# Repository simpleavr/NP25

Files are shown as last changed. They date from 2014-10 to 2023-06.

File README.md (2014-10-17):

NP Calculator Emulator
======================
Nonpariel Physical (NP) is an standalone calculator microcode emulator

Features
_________________
* selectable rom from HP-21, HP-25C and HP-33C.
* press-n-hold + switch on to select one of the three ROMSs.
* a setup menu to set the default ROM to use, plus ability to set speed (fast / slow).
* both 25C and 33C programs are stored separately.
* a greetings message set and show, handy as a gift item

Description
___________

Compile w/ (example only, substitute w/ your setup path)

/msp430-gcc -Os -Wall -ffunction-sections -fdata-sections -fno-inline-small-functions -Wl,-Map=np25.map,--cref -Wl,--relax -Wl,--gc-sections -I /cygdrive/c/mspgcc-20120406-p20120502/bin/../msp430/include -mmcu=msp430g2553 -o np25.elf np25.c

October 2014, cc
* major code clean-up
* includes power-on switchable roms for 21, 25C and 33C
* allow defaults (rom and speed) be saved
* add greeting message
* rom_34c.h, rom for 34C is included for further development only, not emulated at this version

September 2014, cc
* this is a preview release upon request, project is not bugs free.
* based on TI msp430g25x3 mcu, 16KB flash, 512B ram
* based on work from Eric Smith's nonpariel
* emualtes woodstock or spice core
* this is a hobby project not suitable for any use.
* please observe same GPL licensing terms as the original Nonpariel package
* notice from orignal Nonpareil package

Copyright 1995, 2003, 2004, 2005 Eric L. Smith <eric@brouhaha.com>

Nonpareil is free software; you can redistribute it and/or modify it
under the terms of the GNU General Public License version 2 as
published by the Free Software Foundation.  Note that I am not
granting permission to redistribute or modify Nonpareil under the
terms of any later version of the General Public License.

Nonpareil is distributed in the hope that it will be useful, but
WITHOUT ANY WARRANTY; without even the implied warranty of
MERCHANTABILITY or FITNESS FOR A PARTICULAR PURPOSE.  See the GNU
General Public License for more details.

You should have received a copy of the GNU General Public License
along with this program (in the file "COPYING"); if not, write to the
Free Software Foundation, Inc., 59 Temple Place - Suite 330, Boston,
MA 02111, USA.

Parts list
__________

* msp430g2553 (or other G series dip 20pin devices w/ 16k flash)
* 2x sparkfun 4 digit bubble led module
* 32x tactile buttons
* 1x CR2032 SMD battery holder
* 1x 47k, 1x 1k resistors
* 2x 100nF (104), 1x 1nF (102) capacitor

Application Notes
_________________

* press-n-hold 1st row, 5th column (from top) for hp33C
* press-n-hold 2nd row, 5th column for hp25C
* press-n-hold 3nd row, 5th column for hp21
* press-n-hold 4th row, 4th column for version info
* press-n-hold 1st row, 4th column to show greetings
* press-n-hold 1st row, 3rd column to edit greetings, use 0-9 to enter numbers and letters, Run/Stop to advance digit, Cls to abandon entry
* press-n-hold Pgm/Run toggle button to edit default startup settings, use 'F' key to select rom, 'G' key to select speed, Pgm/Run will save setting and exit setup

Schematic
_________

    * runs off 3V button cell

               MSP430G25x3
             -----------------    
         /|\|                 |  
          | |                 | 
          --|RST  digit 0 P2.6|--\
            |     digit 1 P1.0|--\       digits bus (12)
            |     digit 2 P2.7|-----//--+---------+
            |     digit 3 P1.1|--/      |         ~  3 units of 4 digits bubble led
            |     digit 4 P1.2|--/      |         |
            |     digit 5 P1.3|--/      |    +---------+ +---------+ +---------+
            |     digit 6 P2.0|--/      |    | % % % % | | % % % % | | % % % % |----+
            |     digit 7 P1.4|--/      ~    +---------+ +---------+ +---------+    |
            |     digit 8 P1.5|--/      |                                           |
            |     digit 9 P2.1|--/      | digits bus x 3 scan lines                 |
            |     digit a P1.6|--/      +-----+-----+---/ ~~ /--+-----+-----+-----+ |
            |     digit b P1.7|--/  _=_ | _=_ | _=_ | _/ ~~ /=_ | _=_ | _=_ | _=_ | |
			|      scan X P2.5|-----o o-+-o o-+-o o-+-/ ~~ /o o-+-o o-+-o o-+-o o-+ |
			|      scan Y P2.4|-----o o-+-o o-+-o o-+/ ~~ /-o o-+-o o-+-o o-+-o o-+ |
			|      scan Z P2.3|-----o o-+-o o-+-o o-/ ~~ /+-o o-+-o o-+-o o-+-o o-+ |
            |                 |                                                     ~
			|                 |      (32 tactile button)                            |
            |                 |                                                     |
			|                 |        +--------+                                   |
			|             P2.2|--+---->|CLK ~CLR|---+---- Vcc                       |
			|                 |  |     |       B|---+                               |
			|                 |  |     |  0(d)QA|-\                                 |
			|                 |  |     |  1(f)QB|-\                segments bus (8) |
			|                 |  -     |  2(b)QC|--------------//-------------------+
			|                 | | |    |  3(a)QD|-/
			|                 | | |1k  |  4(g)QE|-/  74hc164 segment driver
			|                 |  -     |  5(e)QF|-/
			|                 |  |     |  6(c)QG|-/
			|                 |  +---->|A 7(h)QH|-/
			|                 |  |     +--------+
            |                 | === (102)    1 wire shift register via RC delay
            |                 | ===  1nF	 to shift 1, Hi-Low-Hi
            +-----------------+  |           to shift 0, Hi-Looooooow-Hi (>20us Lo)
                                ___
                                ///

Additional Notes
________________

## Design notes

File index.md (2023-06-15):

## NP25 Calculator

**msp430 Based Calculator Emulator for the HP-21, HP-25C, and HP-33C Calculators.**

<iframe width="560" height="315" src="https://www.youtube.com/embed/WwPM0slZro4" frameborder="0" allow="autoplay; encrypted-media" allowfullscreen></iframe>
<br><br>

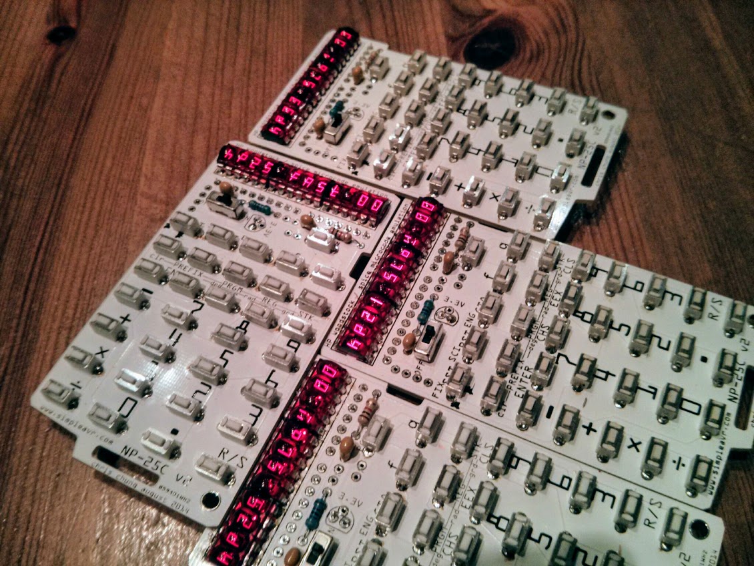
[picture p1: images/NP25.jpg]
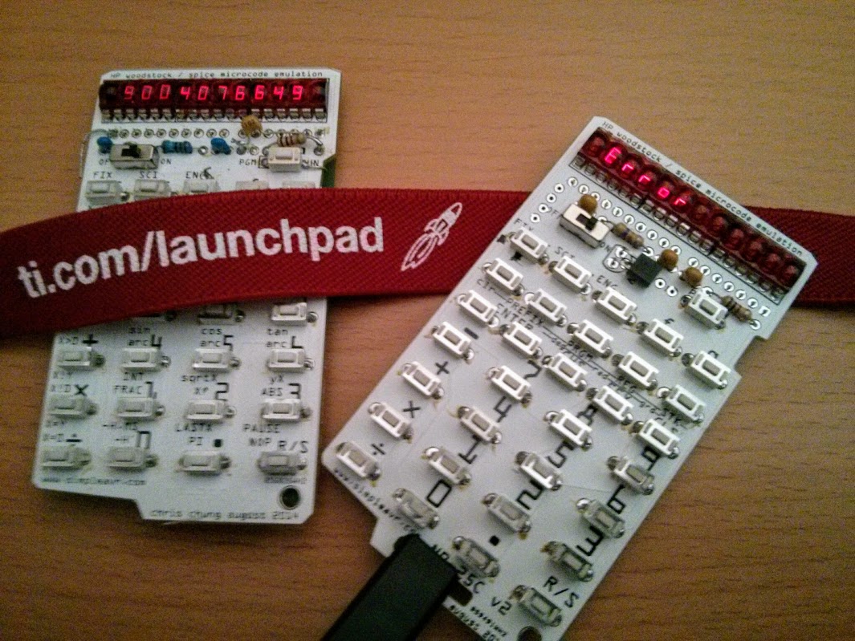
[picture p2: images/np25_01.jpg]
  

### Description

This is a hardware realization of Eric Smith's Nonpareil microcode simulator. 

The objective of the project is to re-create popular 70's RPN calculators such as the HP Woodstock and Spice series. 

Another goal of this project is to have the design as simple as possible so that the project can be re-produced by the average electronic hobbyist. 

A low power MSP430G2553 is used in this project. The DIP profile allows easy soldering. Only through-hole components are used. LED multiplexing is done w/ a 74hc164 shift register. LED modules are direct driven w/ pulsing to eliminate the need of current drivers. 

LED modules are used to mimic the original 70's calculators and gives a retro look to the end product. 

### Application Notes

- press-n-hold 1st row, 5th column (from top) for hp33C
- press-n-hold 2nd row, 5th column for hp25C
- press-n-hold 3nd row, 5th column for hp21
- press-n-hold 4th row, 4th column for version info
- press-n-hold 1st row, 4th column to show greetings
- press-n-hold 1st row, 3rd column to edit greetings, use 0-9 to enter numbers and letters, Run/Stop to advance digit, Cls to abandon entry
- press-n-hold Pgm/Run toggle button to edit default startup settings, use 'F' key to select rom, 'G' key to select speed, Pgm/Run will save setting and exit setup

### Parts and Components

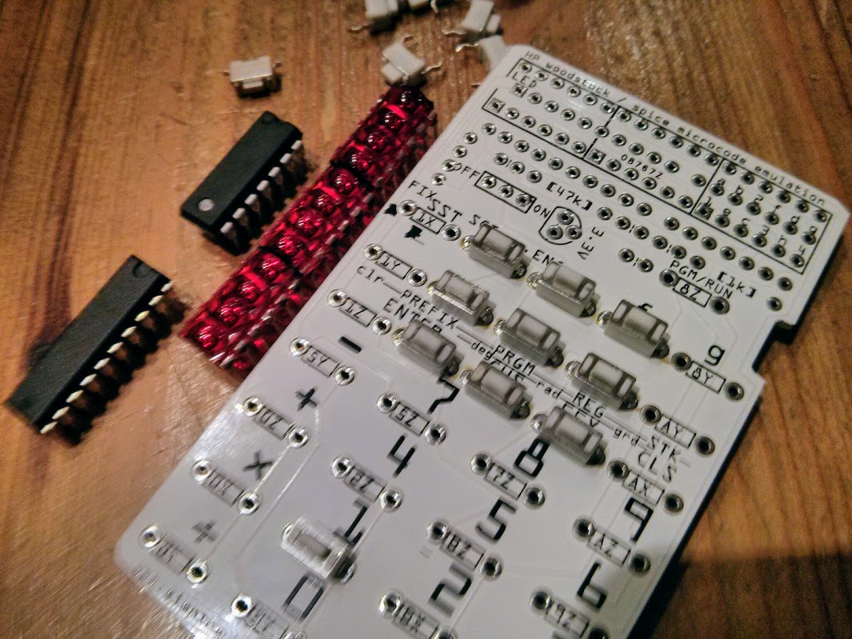
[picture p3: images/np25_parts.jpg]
 

- 1× MSP430G25x3, TI 16bit MCU w/ 16K Flash 512 byte RAM
- 1× 74HC164, TTL shift register
- 3× HP QDSP-6064 LED Module from Sparkfun, 4 digit 7 segment led module
- 32× SMT Tactile Button 6x3mm, May be substituted w/ through-hole buttons
- 1× CR2032 Battery Holder

### Schematic

```
* runs off 3V button cell

           MSP430G25x3
         -----------------
     /|\|                 |
      | |                 |
      --|RST  digit 0 P2.6|--\
        |     digit 1 P1.0|--\       digits bus (12)
        |     digit 2 P2.7|-----//--+---------+
        |     digit 3 P1.1|--/      |         ~  3 units of 4 digits bubble led
        |     digit 4 P1.2|--/      |         |
        |     digit 5 P1.3|--/      |    +---------+ +---------+ +---------+
        |     digit 6 P2.0|--/      |    | % % % % | | % % % % | | % % % % |----+
        |     digit 7 P1.4|--/      ~    +---------+ +---------+ +---------+    |
        |     digit 8 P1.5|--/      |                                           |
        |     digit 9 P2.1|--/      | digits bus x 3 scan lines                 |
        |     digit a P1.6|--/      +-----+-----+---/ ~~ /--+-----+-----+-----+ |
        |     digit b P1.7|--/  _=_ | _=_ | _=_ | _/ ~~ /=_ | _=_ | _=_ | _=_ | |
        |      scan X P2.5|-----o o-+-o o-+-o o-+-/ ~~ /o o-+-o o-+-o o-+-o o-+ |
        |      scan Y P2.4|-----o o-+-o o-+-o o-+/ ~~ /-o o-+-o o-+-o o-+-o o-+ |
        |      scan Z P2.3|-----o o-+-o o-+-o o-/ ~~ /+-o o-+-o o-+-o o-+-o o-+ |
        |                 |                                                     ~
        |                 |      (32 tactile button)                            |
        |                 |                                                     |
        |                 |        +--------+                                   |
        |             P2.2|--+---->|CLK ~CLR|---+---- Vcc                       |
        |                 |  |     |       B|---+                               |
        |                 |  |     |  0(d)QA|-\                                 |
        |                 |  |     |  1(f)QB|-\                segments bus (8) |
        |                 |  -     |  2(b)QC|--------------//-------------------+
        |                 | | |    |  3(a)QD|-/
        |                 | | |1k  |  4(g)QE|-/  74hc164 segment driver
        |                 |  -     |  5(e)QF|-/
        |                 |  |     |  6(c)QG|-/
        |                 |  +---->|A 7(h)QH|-/
        |                 |  |     +--------+
        |                 | === (102)    1 wire shift register via RC delay
        |                 | ===  1nF	 to shift 1, Hi-Low-Hi
        +-----------------+  |           to shift 0, Hi-Looooooow-Hi (>20us Lo)
                            ___
                            ///
```

### Printed Circuit Board

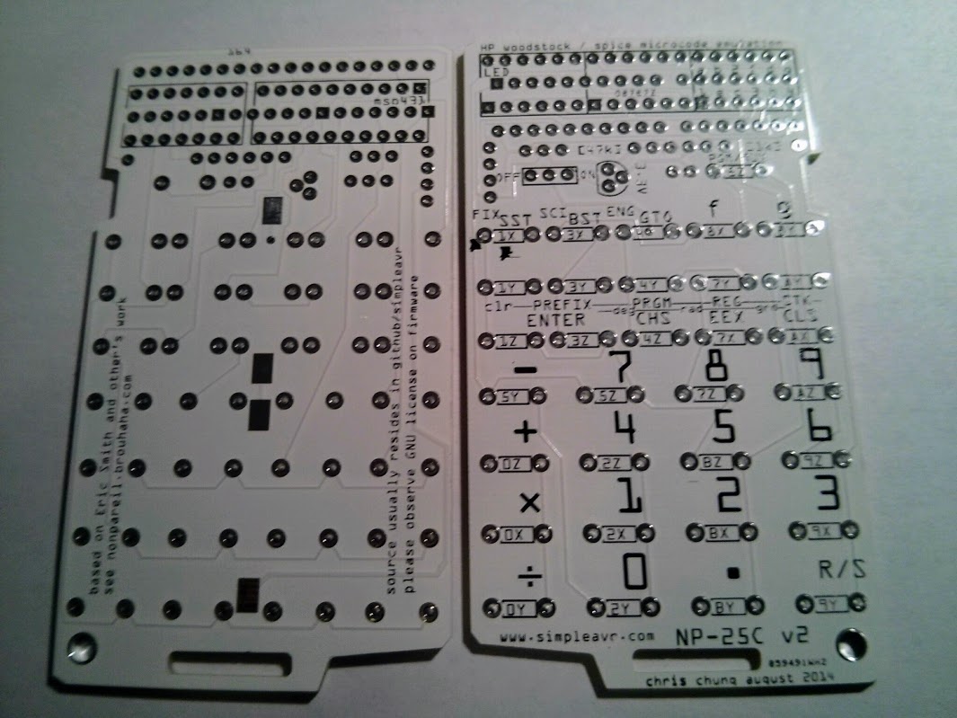
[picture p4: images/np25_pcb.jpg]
 

Create PCB board from the Fritzing design file included in my [github repository](https://github.com/simpleavr/NP25).

You will need to install [Fritzing](http://fritzing.org/home/) and learn how to use it.

Fabricate PCB yourself or order from a FAB house (export Gerber files from Fritzing).

Acquire parts from the components list.

### Soldering

The two layer PCB was designed to minimize component space, and as such, components are placed on both side of the PCB. The ICs and LED modules actually intrudes into each other's footprint as they are through hole components. To address this issue, both the ICs and the LED modules need to have their pins trimmed so that they do not protrude into the other side of the PCB.

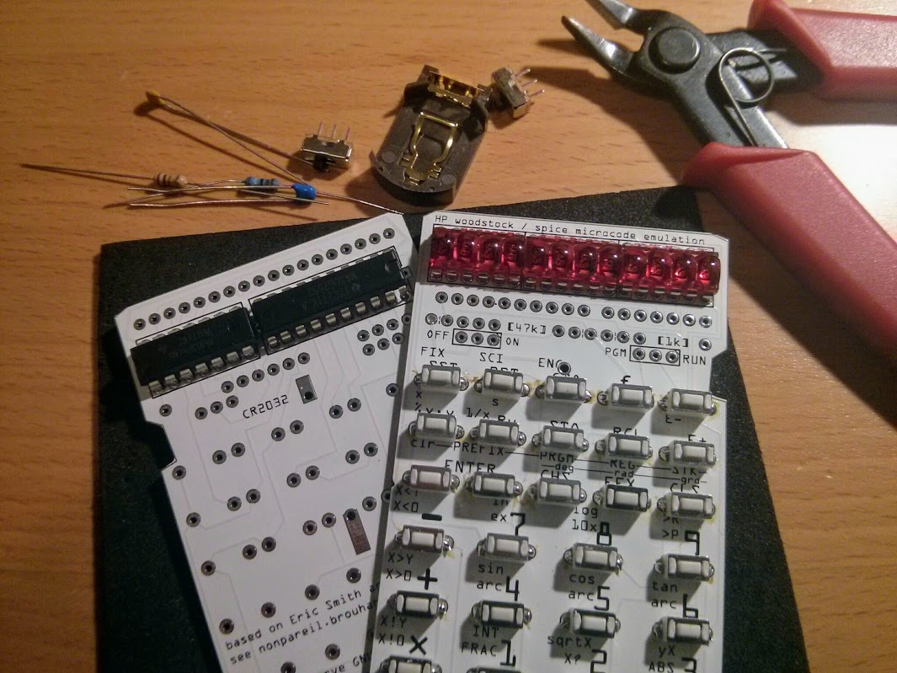
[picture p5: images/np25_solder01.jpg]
 

It is best to place and solder the LED modules first. There are three of them and when finished soldering, use a wire cutter / trimmer to trim off the pins on the other side. This will allow proper placement of the ICs.

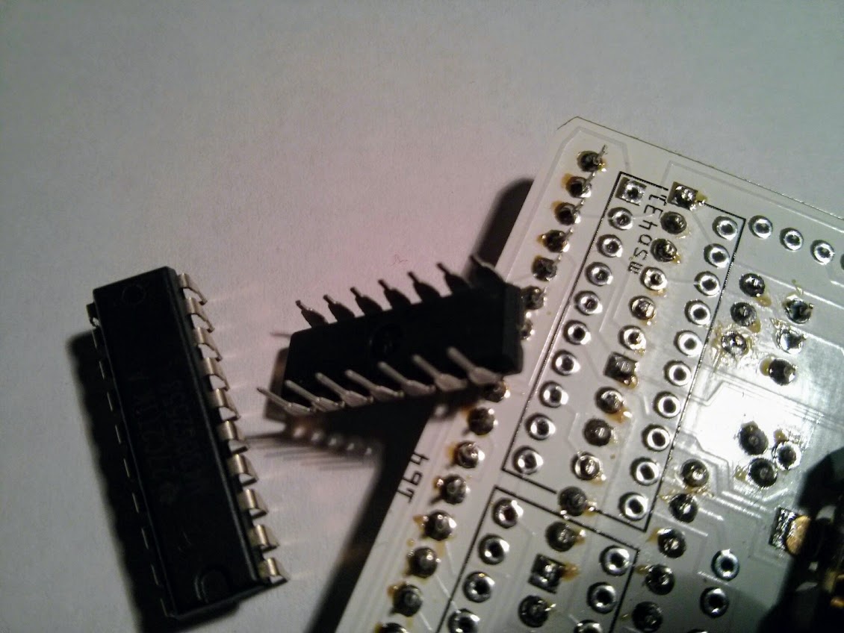
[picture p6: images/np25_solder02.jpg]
 

Next we need to trim the IC pins before placing them onto the PCB. As the other side of the through holes are blocked by the LED modules, they will not fit without trimming the pins.

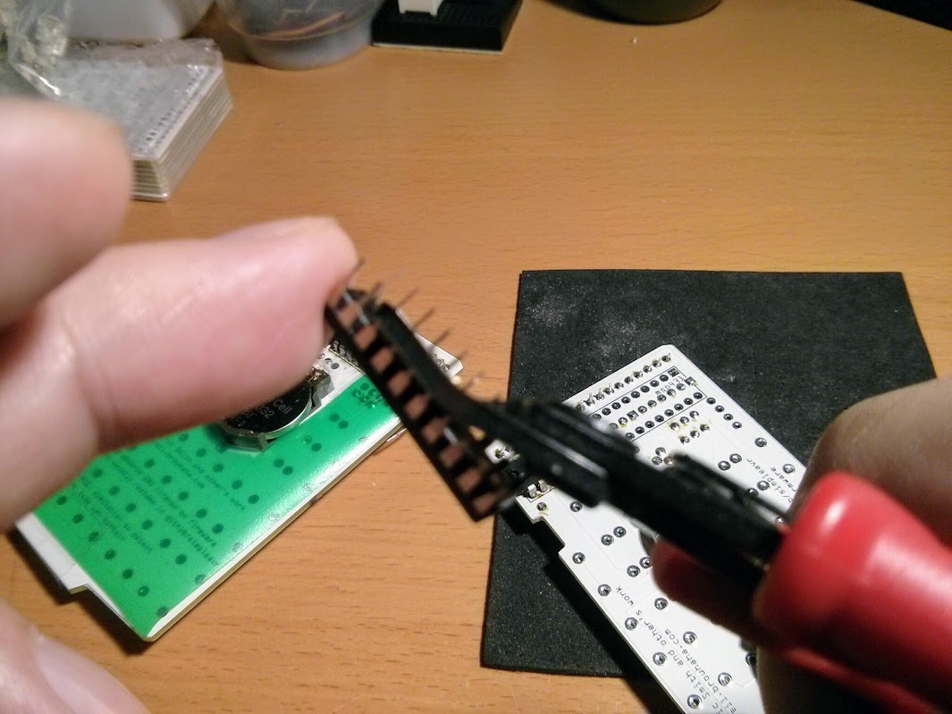
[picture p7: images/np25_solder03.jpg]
 

With the ICs placed on the PCB. We could commence soldering them. This has to be done on the IC component (back) side instead of the usual solder (front) side. This is because the LED modules on the front side block the holes.

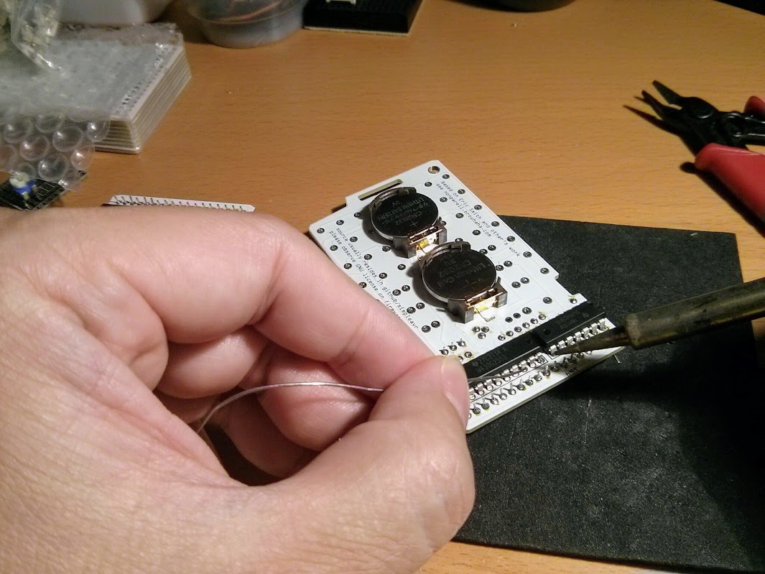
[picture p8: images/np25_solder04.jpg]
 

The rest of the components including the tactile switches and other passive components can be soldered the usual way.

### Software and Programming Tools

Acquire a MSP430 MCU programmer. We need this to program the MCU. Easiest and least expensive way is to get a [TI LaunchPad G2](http://www.ti.com/tool/MSP-EXP430G2) and use it as a programmer.

Download and install GCC compiler for MSP430. There are instructions on the web. You can also [install Energia](http://energia.nu) and use the GCC compiler in the bundle.

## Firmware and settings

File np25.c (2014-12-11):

/*

Chris Chung August 2014, simpleavr@gmail.com
nonpariel physical (NP) is an standalone calculator microcode emulator;

Compile w/ (example only, substitute w/ your setup path)

/msp430-gcc -Os -Wall -ffunction-sections -fdata-sections -fno-inline-small-functions -Wl,-Map=np25.map,--cref -Wl,--relax -Wl,--gc-sections -I /cygdrive/c/mspgcc-20120406-p20120502/bin/../msp430/include -mmcu=msp430g2553 -o np25.elf np25.c

September 2014, cc
. this is a preview release upon request, project is not bugs free.

. based on TI msp430g25x3 mcu, 16KB flash, 512B ram
. based on work from Eric Smith's nonpariel
. emualtes woodstock or spice core
. this is a hobby project not suitable for any use.
. please observe same GPL licensing terms as the original Nonpariel package
. notice from orignal Nonpareil package

Copyright 1995, 2003, 2004, 2005 Eric L. Smith <eric@brouhaha.com>

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
You should have received a copy of the GNU General Public License
along with this program (in the file "COPYING"); if not, write to the
Free Software Foundation, Inc., 59 Temple Place - Suite 330, Boston,
MA 02111, USA.
*/

//#define C_SPICE
#define EMBEDDED
#define C_STANDALONE

#include <inttypes.h>
#include <stdbool.h>
#include <stdint.h>
#include <stdio.h>
#include <stdlib.h>
#include <string.h>

#ifdef EMBEDDED

#define G2553
#define MHZ	12

#include <msp430.h>
//#include "../local/common.h"
//
#define ___use_cal_clk(x)	\
BCSCTL1 = CALBC1_##x##MHZ;	\
DCOCTL  = CALDCO_##x##MHZ;

#define __use_cal_clk(x)	___use_cal_clk(x)
//

#ifdef C_STANDALONE
static volatile uint16_t _ticks = 0;
static volatile uint8_t _clicks = 1;

/*

               MSP430G25x3
             -----------------    
         /|\|                 |  
          | |                 | 
          --|RST  digit 0 P2.6|--\
            |     digit 1 P1.0|--\       digits bus (12)
            |     digit 2 P2.7|-----//--+---------+
            |     digit 3 P1.1|--/      |         ~  3 units of 4 digits bubble led
            |     digit 4 P1.2|--/      |         |
            |     digit 5 P1.3|--/      |    +---------+ +---------+ +---------+
            |     digit 6 P2.0|--/      |    | % % % % | | % % % % | | % % % % |----+
            |     digit 7 P1.4|--/      ~    +---------+ +---------+ +---------+    |
            |     digit 8 P1.5|--/      |                                           |
            |     digit 9 P2.1|--/      | digits bus x 3 scan lines                 |
            |     digit a P1.6|--/      +-----+-----+---/ ~~ /--+-----+-----+-----+ |
            |     digit b P1.7|--/  _=_ | _=_ | _=_ | _/ ~~ /=_ | _=_ | _=_ | _=_ | |
			|      scan X P2.5|-----o o-+-o o-+-o o-+-/ ~~ /o o-+-o o-+-o o-+-o o-+ |
			|      scan Y P2.4|-----o o-+-o o-+-o o-+/ ~~ /-o o-+-o o-+-o o-+-o o-+ |
			|      scan Z P2.3|-----o o-+-o o-+-o o-/ ~~ /+-o o-+-o o-+-o o-+-o o-+ |
            |                 |                                                     ~
			|                 |      (32 tactile button)                            |
            |                 |                                                     |
			|                 |        +--------+                                   |
			|             P2.2|--+---->|CLK ~CLR|---+---- Vcc                       |
			|                 |  |     |       B|---+                               |
			|                 |  |     |  0(d)QA|-\                                 |
			|                 |  |     |  1(f)QB|-\                segments bus (8) |
			|                 |  -     |  2(b)QC|--------------//-------------------+
			|                 | | |    |  3(a)QD|-/
			|                 | | |1k  |  4(g)QE|-/  74hc164 segment driver
			|                 |  -     |  5(e)QF|-/
			|                 |  |     |  6(c)QG|-/
			|                 |  +---->|A 7(h)QH|-/
			|                 |  |     +--------+
            |                 | === (102)    1 wire shift register via RC delay
            |                 | ===  1nF	 to shift 1, Hi-Low-Hi
            +-----------------+  |           to shift 0, Hi-Looooooow-Hi (>20us Lo)
                                ___
                                ///

               74hc164
               o---------+
               |A     Vcc|
               |B      QH|
               |QA     QG|
               |QB     QF|
               |QC     QE|
               |QD   ~CLR|
               |Gnd   CLK|
               +---------+

	4 digit bubble led from sparkfun
    +--+--+--+--+--+ 
   |a  b  2  f  d  g|
   |1  e  c  3  h  4|
    +--+--+--+--+--+ 

	msp430g25x3 pinout (a=port1, b=port2)
    +--+--+--+--+--+--+--+--+--+ 
   |- b6 b7 CK IO a7 a6 b5 b4 b3|
   |                            |
   |+ a0 a1 a2 a3 a4 a5 b0 b1 b2|
    o--+--+--+--+--+--+--+--+--+ 
*/


#define C_PCB

#ifdef C_PCB

static const 
//__attribute__ ((section (".data_fe"))) 
uint8_t digit_map_p1[] = {
	0x00, 1<<0, 0x00, 1<<1,
	1<<2, 1<<3, 0x00, 1<<4,
	1<<5, 0x00, 1<<6, 1<<7,
};

static const 
//__attribute__ ((section (".data_fe"))) 
const uint8_t digit_map_p2[] = {
	1<<6, 0x00, 1<<7, 0x00,
	0x00, 0x00, 1<<0, 0x00,
	0x00, 1<<1, 0x00, 0x00,
};

#define CLK_LOW	P2OUT &= ~BIT2
#define CLK_HI	P2OUT |= BIT2

#define SPIN	P2IN
#define SPOUT	P2OUT
#define SPREN	P2REN
#define SPDIR	P2DIR

#define SCANX	BIT5
#define SCANY	BIT4
#define SCANZ	BIT3
#define ALL_SCANS	(SCANX|SCANY|SCANZ)

#define SEG_D	BIT0
#define SEG_F	BIT1
#define SEG_B	BIT2
#define SEG_A	BIT3
#define SEG_G	BIT4
#define SEG_E	BIT5
#define SEG_C	BIT6
#define SEG_H	BIT7

#else

static const uint8_t digit_map_p1[] = {
	1<<0, 1<<7, 1<<1, 1<<2,
	0, 0, 0, 0,
	0, 0, 0, 0,
};

static const uint8_t digit_map_p2[] = {
	0, 0, 0, 0,
	1<<0, 1<<1, 1<<2, 1<<3,
	1<<4, 1<<5, 1<<6, 1<<7,
};

#define CLK_LOW	P1OUT &= ~BIT3
#define CLK_HI	P1OUT |= BIT3

#define SPIN	P1IN
#define SPOUT	P1OUT
#define SPREN	P1REN
#define SPDIR	P1DIR
#define SCANX	BIT4
#define SCANY	BIT5
#define SCANZ	BIT6
#define ALL_SCANS	(SCANX|SCANY|SCANZ)

#define SEG_A	BIT0
#define SEG_B	BIT5
#define SEG_C	BIT2
#define SEG_D	BIT6
#define SEG_E	BIT3
#define SEG_F	BIT4
#define SEG_G	BIT7
#define SEG_H	BIT1

#endif

#define ALL_DIGITS_P1	\
   (digit_map_p1[0]|digit_map_p1[1]|digit_map_p1[2]|digit_map_p1[3]|	\
	digit_map_p1[4]|digit_map_p1[5]|digit_map_p1[6]|digit_map_p1[7]|	\
	digit_map_p1[8]|digit_map_p1[9]|digit_map_p1[10]|digit_map_p1[11])
#define ALL_DIGITS_P2	\
   (digit_map_p2[0]|digit_map_p2[1]|digit_map_p2[2]|digit_map_p2[3]|	\
	digit_map_p2[4]|digit_map_p2[5]|digit_map_p2[6]|digit_map_p2[7]|	\
	digit_map_p2[8]|digit_map_p2[9]|digit_map_p2[10]|digit_map_p2[11])

static const 
//__attribute__ ((section (".data_fe"))) 
uint8_t seg_map[] = {
   SEG_A|SEG_B|SEG_C|SEG_D|SEG_E|SEG_F,
   SEG_B|SEG_C,
   SEG_A|SEG_B|SEG_D|SEG_E|SEG_G,
   SEG_A|SEG_B|SEG_C|SEG_D|SEG_G,
   SEG_B|SEG_C|SEG_F|SEG_G,
   SEG_A|SEG_C|SEG_D|SEG_F|SEG_G,
   SEG_A|SEG_C|SEG_D|SEG_E|SEG_F|SEG_G,
   SEG_A|SEG_B|SEG_C,
   SEG_A|SEG_B|SEG_C|SEG_D|SEG_E|SEG_F|SEG_G,
   SEG_A|SEG_B|SEG_C|SEG_D|SEG_F|SEG_G,
   SEG_E|SEG_G,	// r, H/F, o, p, e, blank
//#ifdef C_SPICE
//#else
   SEG_A|SEG_E|SEG_F|SEG_G, 			
//#endif
   SEG_C|SEG_D|SEG_E|SEG_G,
   SEG_A|SEG_B|SEG_E|SEG_F|SEG_G,
   SEG_A|SEG_D|SEG_E|SEG_F|SEG_G,
   0x00,
   SEG_B|SEG_C|SEG_E|SEG_F|SEG_G, 		// for spice as 0xb
   //________________ a to z
   SEG_A|SEG_B|SEG_C|SEG_E|SEG_F|SEG_G,	// A
   SEG_C|SEG_D|SEG_E|SEG_F|SEG_G,		// b
   SEG_D|SEG_E|SEG_G,					// c
   SEG_B|SEG_C|SEG_D|SEG_E|SEG_G,		// d
   SEG_A|SEG_D|SEG_E|SEG_F|SEG_G,		// E
   SEG_A|SEG_E|SEG_F|SEG_G,				// F
   SEG_A|SEG_C|SEG_D|SEG_E|SEG_F,		// G
   SEG_C|SEG_E|SEG_F|SEG_G,				// h
   SEG_E|SEG_F,							// i
   SEG_B|SEG_C|SEG_D,					// j
   SEG_D|SEG_F|SEG_G,					// k
   SEG_D|SEG_E|SEG_F,					// L
   SEG_A|SEG_C|SEG_E,					// m
   SEG_C|SEG_E|SEG_G,					// n
   SEG_C|SEG_D|SEG_E|SEG_G,				// o
   SEG_A|SEG_B|SEG_E|SEG_F|SEG_G,		// P
   SEG_A|SEG_B|SEG_C|SEG_F|SEG_G,		// q
   SEG_E|SEG_G,							// r
   SEG_A|SEG_C|SEG_D|SEG_F|SEG_G,		// S
   SEG_D|SEG_E|SEG_F|SEG_G,				// t
   SEG_C|SEG_D|SEG_E,					// u
   SEG_C|SEG_D|SEG_E|SEG_F,				// v
   SEG_B|SEG_D|SEG_F,					// w
   SEG_B|SEG_C|SEG_E|SEG_F|SEG_G,		// X
   SEG_B|SEG_C|SEG_D|SEG_F|SEG_G,		// y
   SEG_A|SEG_B|SEG_D|SEG_E|SEG_G,		// Z
   SEG_A|SEG_D|SEG_E|SEG_F|SEG_G,		// [
   SEG_A|SEG_B|SEG_F,					// ^
   SEG_A|SEG_B|SEG_C|SEG_D|SEG_G,		// ]
   SEG_C|SEG_F|SEG_G,					// blackslash
   SEG_D,								// _
   SEG_B,								// '
};

/*
keys layout
	// 25
	" SST  BST  GTO   F    G ",	// 0xb3, 0xb2, 0xb1, 0xb0, 0xb4
	" X.Y  RV   STO  RCL  E+ ",	// 0x43, 0x42, 0x41, 0x40, 0x44
	" ETR  ETR  CHS  EEX  CLX",	// 0xd3,       0xd1, 0xd0, 0xd4
	"  -     7     8      9  ",	// 0x63, 0x62, 0x61, 0x60
	"  +     4     5      6  ",	// 0x93, 0x92, 0x91, 0x90
	"  x     1     2      3  ",	// 0x73, 0x72, 0x71, 0x70
	"  /     0     .     R/S ", // 0xa3, 0xa2, 0xa1, 0xa0

	// 34c
	"  A    B   GSB   F    G ",	// 0x34, 0x33, 0x32, 0x31, 0x30
	" X.Y  GTO  STO  RCL   h ",	// 0x94, 0x93, 0x92, 0x91, 0x90
	" ETR  ETR  CHS  EEX  CLX",	// 0x73,       0x72, 0x71, 0x70
	"  -     7     8      9  ",	// 0xa3, 0xa2, 0xa1, 0xa0
	"  +     4     5      6  ",	// 0x43, 0x42, 0x41, 0x40
	"  x     1     2      3  ",	// 0xd3, 0xd2, 0xd1, 0xd0
	"  /     0     .     R/S ", // 0x63, 0x62, 0x61, 0x60

raw scancode on pcb version, code is digit * 4 + [123] for [XYZ]

                       [8Z]	            ,35,
   [1X] [3X] [4X] [8X] [8Y]	, 5,13,17,33,34,
   [1Y] [3Y] [4Y] [7Y] [aY] , 6,14,18,30,42,
   [1Z] [3Z] [4Z] [7X] [aX] , 7,15,19,29,41,
   [5Y]  [5Z]   [7Z]   [aZ] ,22,   23,31,43,
   [0Z]  [2Z]   [bZ]   [9Z] , 3,   11,47,39,
   [0X]  [2X]   [bX]   [9X] , 1,    9,45,37,
   [0Y]  [2Y]   [bY]   [9Y] , 2,   10,46,38,
   scan lines X, Y, Z

*/
#else

#include "../local/uart.h"
#define putchar(x)	uart_putc(x)

#endif

#else

#include <unistd.h>
#include <sys/select.h>
#include <termios.h>

#endif

#ifdef C_STANDALONE
#else 

static const uint8_t key_map[256] = {
	// 25c
	0x00, 0x00, 0x00, 0x00, 0x00, 0x00, 0x00, 0x00, 0x00, 0x00, 0x00, 0x00, 0x00, 0x90, 0x00, 0x00,	// 0x0f
	0x00, 0x00, 0x00, 0x00, 0x00, 0x00, 0x00, 0x00, 0x00, 0x00, 0x00, 0x00, 0x00, 0x00, 0x00, 0x00,	// 0x1f
	0xd3, 0x00, 0x00, 0x00, 0x00, 0x00, 0x00, 0x00, 0x00, 0x00, 0x73, 0xa3, 0x00, 0x63, 0x91, 0x93,	// 0x2f
	0x92, 0x72, 0x71, 0x70, 0xa2, 0xa1, 0xa0, 0x62, 0x61, 0x60, 0x00, 0x00, 0x00, 0x00, 0x00, 0x00,	// 0x3f
	0x00, 0x00, 0x00, 0x00, 0x00, 0x00, 0x00, 0x00, 0x00, 0x00, 0x00, 0x00, 0x00, 0x00, 0x00, 0x00,	// 0x4f
	0x00, 0x00, 0x00, 0x00, 0x00, 0x00, 0x00, 0x00, 0x00, 0x00, 0x00, 0x00, 0x00, 0x00, 0x00, 0x00,	// 0x5f
	0x00, 0xb3, 0x00, 0xd4, 0xb1, 0x41, 0xb0, 0xb4, 0x00, 0x00, 0x00, 0x00, 0x00, 0x00, 0x00, 0x00,	// 0x6f
	0x00, 0x43, 0x40, 0xb2, 0x44, 0x00, 0x00, 0x42, 0xd0, 0x00, 0xd1, 0x00, 0x00, 0x00, 0x00, 0x00,	// 0x7f
	// 34c
	0x00, 0x00, 0x00, 0x00, 0x00, 0x00, 0x00, 0x00, 0x00, 0x00, 0x00, 0x00, 0x00, 0x40, 0x00, 0x00,	// 0x0f
	0x00, 0x00, 0x00, 0x00, 0x00, 0x00, 0x00, 0x00, 0x00, 0x00, 0x00, 0x00, 0x00, 0x00, 0x00, 0x00,	// 0x1f
	0x73, 0x00, 0x00, 0x00, 0x00, 0x00, 0x00, 0x00, 0x00, 0x00, 0xd3, 0x63, 0x00, 0xa3, 0x41, 0x43,	// 0x2f
	0x42, 0xd2, 0xd1, 0xd0, 0x62, 0x61, 0x60, 0xa2, 0xa1, 0xa0, 0x00, 0x00, 0x00, 0x00, 0x00, 0x00,	// 0x3f
	0x00, 0x00, 0x00, 0x00, 0x00, 0x00, 0x00, 0x00, 0x00, 0x00, 0x00, 0x00, 0x00, 0x00, 0x00, 0x00,	// 0x4f
	0x00, 0x00, 0x00, 0x00, 0x00, 0x00, 0x00, 0x00, 0x00, 0x00, 0x00, 0x00, 0x00, 0x00, 0x00, 0x00,	// 0x5f
	0x00, 0x34, 0x00, 0x70, 0x32, 0x92, 0x31, 0x30, 0x00, 0x00, 0x00, 0x00, 0x00, 0x00, 0x00, 0x00,	// 0x6f
	0x00, 0x94, 0x91, 0x33, 0x90, 0x00, 0x00, 0x93, 0x71, 0x00, 0x72, 0x00, 0x00, 0x00, 0x00, 0x00,	// 0x7f
};

#endif

#define __USE_RAM	32	// our highest model 33c has 32 units

#include "rom_21.h"
#include "rom_25.h"
#include "rom_33c.h"
#include "np25.h"

static volatile uint8_t _pgm_run=1;
static volatile uint8_t _state=0;
static volatile uint8_t _key=0;
static int8_t _greetings[12];

#define ST_RAM_LOADED 		BIT7
#define ST_KEY_PRESSED		BIT6
#define ST_KEY_RELEASED		BIT5
#define ST_ALPHA_MSG		BIT4
#define ST_HW_SLOW			BIT3
#define ST_HW_TEST			BIT2
#define ST_ROM_BIT1			BIT1
#define ST_ROM_BIT0  		BIT0
#define ST_ROM				(ST_ROM_BIT1|ST_ROM_BIT0)

/*
  base=142
  64+64+64
  4 blocks 112+112+112+112=448
  142 + [224] = 366 used + 32 ram_reserve = 392
  > offset 224
  get block 2+3 (224) write 192 to info BCD, 32 into ram_reserve
*/

//________________________________________________________________________________
void flash_write(uint8_t bank, char *src, uint8_t cnt) {
	char *flash = (char*) 0x1040;
	if (bank) flash += 0x40;
	FCTL2 = FWKEY+FSSEL0+FN2;
	FCTL1 = FWKEY+ERASE;
	FCTL3 = FWKEY;
	*flash = 0;

	FCTL1 = FWKEY+WRT; 

	uint8_t i;
	for (i=0;i<cnt;i++) *flash++ = *src++;
	*flash++ = _state;
	if (!bank)
		for (i=0;i<12;i++) *flash++ = _greetings[i];

	FCTL1 = FWKEY;
	FCTL3 = FWKEY+LOCK; 
}

#define _MSG_POS	act_reg->f
#define _MSG_LEN	act_reg->p
#define _EDIT_POS 	act_reg->key_buf
#define _MSG_PTR	act_reg->rom
#define _LAST_KEY	act_reg->flags

//volatile uint8_t _MSG_POS=0, _MSG_LEN=0;
//volatile const char *_MSG_PTR=0;

/*
hp-25 5
pos 11 digit 0(x).......     11(h)
pos 10 digit 0(x).......10(h)11(p)
pos 2 digit 0(x)...9(h)10(p)11(-)
*/


//________________________________________________________________________________
uint8_t char_at_digit(uint8_t digit) {
	uint8_t seg=0;
	if ((digit==_EDIT_POS) && (_ticks&0x200)) return 0;
	if (digit>=_MSG_POS) {
		uint8_t i = digit-_MSG_POS;
		if (i < _MSG_LEN) {
			if (_MSG_PTR[i] >= '0') { if (i >= 'A')
					seg = seg_map[_MSG_PTR[i] - 32 - '0'];
				else
					seg = seg_map[_MSG_PTR[i] - '0'];
			}//if
		}//if
	}//if
	return seg;
}
//________________________________________________________________________________
void show_msg(const uint8_t *msg, uint8_t delay_units) {

	_MSG_PTR = msg;
	while (*msg++) _MSG_LEN++;
	_MSG_POS = 11;
	_state |= ST_ALPHA_MSG;
	//______ accelerate.....brake 6,5,4,3,2,1,2,3,4,5,6
	//                            b,a,9,8,7,6,5,4,3,2,1
	while (_MSG_POS--) {
		_clicks = _MSG_POS>=6 ? _MSG_POS-5 : 6-_MSG_POS;
		LPM0;
	}//while
	_MSG_POS = 0;

	if (delay_units) _clicks = delay_units;
	LPM0;
	_state &= ~ST_ALPHA_MSG;
}

//________________________________________________________________________________
int main() {

#ifdef EMBEDDED
    WDTCTL  = WDTPW + WDTHOLD; 	// Stop WDT
	__use_cal_clk(MHZ);
	//FCTL2 = FWKEY + FSSEL0 + FN1;	// MCLK/3 for Flash Timing Generator
	FCTL2 = FWKEY + FSSEL0 + FN2;	// for 12Mhz

#ifdef C_STANDALONE

	TA0CCR0  = MHZ * 1000;		// start w/ 1ms
	TA0CCTL0 = CCIE;
	TA0CTL = TASSEL_2 + MC_2;	// SMCLK, cont.

	P1SEL = P2SEL = 0;

	P1OUT = ALL_DIGITS_P1;
	P2OUT = ALL_DIGITS_P2;
	P1DIR = P2DIR = 0xff;

	SPOUT |= ALL_SCANS;
	SPREN |= ALL_SCANS;
	SPDIR &= ~ALL_SCANS;

#else
	uint8_t usage = 0;
	uart_init();
#endif

    __bis_SR_register(GIE);

#else
	set_conio_terminal_mode();

#endif

 
	/*
	key_map['0'] = 0x92; key_map['1'] = 0x72; key_map['2'] = 0x71; key_map['3'] = 0x70;
	key_map['4'] = 0xa2; key_map['5'] = 0xa1; key_map['6'] = 0xa0; key_map['7'] = 0x62;
	key_map['8'] = 0x61; key_map['9'] = 0x60; key_map['.'] = 0x91; key_map['-'] = 0x63;
	key_map['+'] = 0xa3; key_map['*'] = 0x73; key_map['/'] = 0x93; key_map['\r'] = 0x90;	// run/stop
	key_map['a'] = 0xb3; key_map['s'] = 0xb2; key_map['d'] = 0xb1; key_map['f'] = 0xb0; key_map['g'] = 0xb4; // SST BST GTO F   G
	key_map['q'] = 0x43; key_map['w'] = 0x42; key_map['e'] = 0x41; key_map['r'] = 0x40; key_map['t'] = 0x44; // X.Y RV  STO RCL E+
	key_map[' '] = 0xd3; key_map['z'] = 0xd1; key_map['x'] = 0xd0; key_map['c'] = 0xd4;					     // ETR ETR CHS EEX CLX
	*/
#define RAM_OFFSET	(7*9)
#define RAM_SIZE	(7*7)		// 49 program steps

	woodstock_clear_memory();
	//______ load from flash, we just need the status config, but we load everything since
	//       we might need to write it back and flash always write in full blocks
	uint8_t idx = RAM_SIZE + 1 + 12;	// 49 program steps + config byte + 12 byte greeting
	while (idx--) ((char*) act_reg->ram)[idx+RAM_OFFSET] = *((char*) (0x1040+idx));
	_state = ((char*) (act_reg->ram))[RAM_OFFSET+RAM_SIZE] & (ST_HW_SLOW|ST_ROM);

	for (idx=0;idx<12;idx++) _greetings[idx] = ((uint8_t*) act_reg->ram)[RAM_OFFSET+50+idx];
	_MSG_PTR = (uint8_t*) _greetings;

	LPM0;

	while (_key == 35) _state |= ST_HW_TEST;		// pgm key pressed, enter setup

	_EDIT_POS = 99;
	uint8_t save_state = _state;
	switch (_key) {
		//
		case 17: 	// "goto" key for edit easter egg message
			while (!(_state&ST_KEY_RELEASED)) __asm("nop");
			_state &= ~ST_KEY_RELEASED;
			{
				uint8_t *p= (uint8_t*) _MSG_PTR;
				//uint8_t i=0;
				_EDIT_POS = 0;
				_MSG_POS = 0;
				_MSG_LEN = 12;
				_LAST_KEY = 99;
				_state |= ST_ALPHA_MSG;		// start show
				while (1) {
					LPM0;					// wait key
					uint8_t k = _key;
					if (k == 41) break;
					if (k == 38) {
						_EDIT_POS++;
						p++;
						_LAST_KEY = 99;
						if (_EDIT_POS>=12) {
							//__________ the last 12 bytes are the greetings
							flash_write(0, (char*) act_reg->ram + RAM_OFFSET, RAM_SIZE);
							break;
						}//if
					}//if
					switch (k) {
						case 10: k = 0; break;
						case 9:  k = 1; break;
						case 45: k = 2; break;
						case 37: k = 3; break;
						case 11: k = 4; break;
						case 47: k = 5; break;
						case 39: k = 6; break;
						case 23: k = 7; break;
						case 31: k = 8; break;
						case 43: k = 9; break;
						default: k = 10; break;
					}//switch
					const uint8_t key_adv[] = { 'A', 'D', 'G', 'J', 'M', 'P', 'T', 'W', '[', };
					if (k < 10) {
						if (k == _LAST_KEY) {
							if (k >= 2) {
								if (*p <= '9') {
									*p = key_adv[k-2];
								}//if
								else {
									*p = *p + 1;
									if (*p == key_adv[k-1])
										*p = '0' + k;
								}//else
							}//if
							else {
								if (k == 0) {
									*p = *p == '0' ? '?' : '0';
								}//if
							}//else
						}//if
						else {
							if (k < 10) {
								*p = '0' + k;
								_LAST_KEY = k;
							}//if
						}//else
					}//if
				}//while
			}
			_state &= ~ST_ALPHA_MSG;
			break;
		//
		case 33: 	// F key, show secret message
			show_msg(_MSG_PTR, 100);
			break;
		// right top, going down on same column
		case 34: 
			_state = 1;
			show_msg((const uint8_t*) "HP33C ROM", 100);
			break;
		case 42: 
			_state = 2;
			show_msg((const uint8_t*) "HP25C ROM", 100);
			break;
		case 41: 
			_state = 3;
			show_msg((const uint8_t*) "HP21 ROM", 100);
			break;
		case 43:
			show_msg((const uint8_t*) "NP25 VER 3", 100);
			break;
	}//switch
	if (save_state&ST_HW_SLOW) _state |= ST_HW_SLOW;

	while (_state&ST_HW_TEST) {
		LPM0;
		switch (_key) {
			case 35: 	// pgm/run key
				_state &= ~ST_HW_TEST; 
				flash_write(0, (char*) act_reg->ram + RAM_OFFSET, RAM_SIZE);
				break;
			case 33:	// F key to rotate rom
			// 00..01, 01..10, 10..11, 11..01
				if ((_state&ST_ROM)==0x03)
					_state &= ~ST_ROM;
				_state++;
				break;
			case 34:	// G key to toggle fast and slow cpu
				_state ^= ST_HW_SLOW;
				break;
		}//switch
	}//while

	/*
	if ((_state&ST_ROM)==0x02) {	// 25c use alternate rom
		uint8_t i = 7*16 + 1;
		while (i--) ((char*) act_reg->ram)[i] = *((char*) (0x1040+i));
	}//if
	*/

	woodstock_set_rom(_state&ST_ROM);
	woodstock_new_processor();

	_state &= ~(ST_RAM_LOADED|ST_KEY_PRESSED|ST_KEY_RELEASED);

	uint8_t done=0;
#ifdef C_STANDALONE
#else
	uint8_t c=0;
#endif
	uint8_t release_in=0;

	woodstock_set_ext_flag (3, _pgm_run);		// set run mode

	while (!done) {
#ifdef C_STANDALONE
		if (_state) {
			if (_state & ST_KEY_PRESSED) {
				if (!(_state&ST_RAM_LOADED)) {
					//______ lets load ram from flash (pretend continous memory) at 1st key
					//       need to do it here after cpu initialized
					if (_pgm_run && ((_state&ST_ROM) != 0x03)) {
						_state |= ST_RAM_LOADED;
						char *src = (char*) 0x1040;
						uint8_t c = RAM_SIZE;
						if (!(_state&ST_ROM_BIT0)) src += 0x40;		// next infomem block for hp25
						while (c--) ((char*) act_reg->ram)[c+RAM_OFFSET] = *(src + c);
					}//if
				}//if
				if (_key == 35) {
					woodstock_set_ext_flag (3, _pgm_run ^= 1);		// pgm-run toggle
					//___ to run mode, write flash
					if (_pgm_run && ((_state&ST_ROM) != 0x03)) {
						uint16_t des = 0x1040;
						if (!(_state&ST_ROM_BIT0)) des += 0x40;
						flash_write(_state&ST_ROM_BIT0 ? 0 : 1,
							(char*) act_reg->ram + RAM_OFFSET, RAM_SIZE);
					}//if
				}//if
				else {
					//if (session_key_map[_key]) woodstock_press_key(session_key_map[_key]);
					sim_check_key(_key);
				}//else
				_state &= ~ST_KEY_PRESSED;
			}//if
			else if (_state & ST_KEY_RELEASED) {
				woodstock_release_key();
				_state &= ~ST_KEY_RELEASED;
			}//if
		}//if
#else
#ifdef EMBEDDED
		if (c || uart_getc(&c)) {
			//P1OUT ^= BIT0;
			if (!usage) {
				usage = 1;
				uart_puts("\x1b[1;1H");
				uart_puts("\x1b[0J");
				uart_puts("\n\r\n\r\n\r");
				uart_puts(" SST  BST  GTO   F    G \n\r");
				uart_puts(" X.Y  RV   STO  RCL  E+ \n\r");
				uart_puts(" ETR  ETR  CHS  EEX  CLX\n\r");
				uart_puts("  -     7      8      9  \n\r");
				uart_puts("  +     4      5      6  \n\r");
				uart_puts("  x     1      2      4  \n\r");
				uart_puts("  /     0      .     R/S \n\r\n\r");
				uart_puts("\x1b[9A");
			}//if
#else
		if (kbhit()) {
			c = getch();
#endif
			switch (c) {
				case 27: 
					done = 1; 
					break;
				case '\\': 
					woodstock_new_processor();
					_pgm_run = 0;
					break;
				case '=': 
					woodstock_set_ext_flag (3, _pgm_run ^= 1);		// pgm-run toggle
					//if (_pgm_run) flash_write(0xfc00, (char*)act_reg->ram, 7*__USE_RAM);
					break;
				default:
#ifdef C_SPICE
					c += 128;
#endif
					if (key_map[c]) {
						woodstock_press_key(key_map[c]);
						release_in = 10;
					}//if
					break;
			}//switch
			c = 0;
		}//if
#endif
		if (!woodstock_execute_instruction()) break;
		if (release_in) {
			if (release_in == 1) woodstock_release_key();
			release_in--;
		}//if

#ifdef EMBEDDED
		if (_state&ST_HW_SLOW) __delay_cycles(MHZ*150);
#else
		//usleep(100);
#endif
	}//while

	return 0;

}
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

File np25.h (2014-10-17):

/*

Chris Chung August 2014
nonpariel physical (NP) is an standalone calculator microcode emulator;

$Id: proc_woodstock.h 686 2005-05-26 09:06:45Z eric $
Copyright 1995, 2003, 2004, 2005 Eric L. Smith <eric@brouhaha.com>

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
You should have received a copy of the GNU General Public License
along with this program (in the file "COPYING"); if not, write to the
Free Software Foundation, Inc., 59 Temple Place - Suite 330, Boston,
MA 02111, USA.
*/


#define WSIZE 14
#define EXPSIZE 3  // two exponent and one exponent sign digit

typedef uint8_t digit_t;
typedef digit_t reg_t [WSIZE];
typedef digit_t creg_t [WSIZE/2];

#ifdef C_SPICE

#define C_LEFT_SCAN		(WSIZE-2)
#define C_RIGHT_SCAN	3

#else

#define C_LEFT_SCAN 	(WSIZE-1)
#define C_RIGHT_SCAN	2

#endif


#define SSIZE 16
#define STACK_SIZE 2

#define EXT_FLAG_SIZE 16

#define PAGE_SIZE 1024
#define MAX_PAGE 4
#define MAX_BANK 2

typedef uint16_t rom_addr_t;


typedef enum {
	norm,
	branch,
	selftest
} inst_state_t;


#define F_DECIMAL		(1<<0)
#define F_CARRY			(1<<1)
#define F_PREV_CARRY	(1<<2)
#define F_DEL_ROM		(1<<3)
#define F_KEY			(1<<4)
#define F_DISPLAY_ON	(1<<5)
#define F_DISPLAY_14	(1<<6)
#define F_BANK			(1<<7)

typedef struct {
  reg_t a;
  reg_t b;
  reg_t c;
  creg_t y;
  creg_t z;
  creg_t t;
  creg_t m1;
  creg_t m2;

  digit_t f;
  digit_t p;

  uint8_t flags;
  /*
  bool decimal;
  bool carry, prev_carry;
  bool del_rom_flag;
  bool key_flag;      // true if a key is down
  bool display_enable;
  bool display_14_digit;  // true after RESET TWF instruction
  */

  //bool s [SSIZE];                 // ACT flags (status bits)
  //bool ext_flag [EXT_FLAG_SIZE];  // external flags, cause status or CRC bits to get set
  uint16_t ext_flag;  // external flags, cause status or CRC
  uint16_t s;  // ACT flags (status bits)

  uint16_t pc;

  uint16_t del_rom;

  inst_state_t inst_state;

  int16_t sp;  /* stack pointer */
  int16_t stack [STACK_SIZE];

  int16_t prev_pc;  /* used to store complete five-digit octal address of instruction */
  //int crc;
  // keyboard

  uint8_t key_buf;        /* most recently pressed key */

  // display

  //uint8_t left_scan;
  //uint8_t right_scan;
#ifdef C_STANDALONE
#else
  uint8_t display_scan_position;   /* word index, left_scan down to right_scan */
  uint8_t display_digit_position;  /* character index, 0 to MAX_DIGIT_POSITION-1 */
#endif

  //void (* display_scan_fn) (void);

  //void (* op_fcn [1024])(int opcode);

  // ROM:
  /*
  uint8_t bank_exists [MAX_PAGE];  // bitmap
  bool bank;                       // only a single global bank bit
  */
  const uint8_t *rom;
  const uint8_t *rom_ex;
  /*
  bool *rom_exists;
  bool *rom_breakpoint;
  */

  // RAM:
  int16_t ram_addr;  /* selected RAM address */
  creg_t ram[__USE_RAM];
} act_reg_t;

//FIXES
/*

gcc wood.c digit_ops.c

keys layout
	" SST  BST  GTO   F    G ",	// 0xb3, 0xb2, 0xb1, 0xb0, 0xb4
	" X.Y  RV   STO  RCL  E+ ",	// 0x43, 0x42, 0x41, 0x40, 0x44
	" ETR  ETR  CHS  EEX  CLX",	// 0xd3,       0xd1, 0xd0, 0xd4
	"  -     7     8      9  ",	// 0x63, 0x62, 0x61, 0x60
	"  +     4     5      6  ",	// 0xa3, 0xa2, 0xa1, 0xa0
	"  x     1     2      4  ",	// 0x73, 0x72, 0x71, 0x70
	"  /     0     .     R/S ", // 0x93, 0x92, 0x91, 0x90

*/
#define MAX_DIGIT_POSITION 15    /* Classic, Topcat, 67, maybe 19C */


#ifdef C_STANDALONE

typedef uint8_t segment_bitmap_t;		// 8 segments for our led
#define CHAR_MINUS	SEG_G
#define CHAR_DOT  	SEG_H

#else

typedef uint16_t segment_bitmap_t;		// 16bit
#define CHAR_MINUS	0x40
#define CHAR_DOT  	0x80
//static segment_bitmap_t last_display_segments[MAX_DIGIT_POSITION];
static segment_bitmap_t _display_segments[MAX_DIGIT_POSITION];
static uint16_t last_seg_crc=0;

#endif

static act_reg_t _act_reg, *act_reg=&_act_reg;

static inline uint8_t arithmetic_base (act_reg_t *act_reg) {
	return (act_reg->flags & F_DECIMAL ? 10 : 16);
}

static void bad_op (int opcode) { }

void reg_zero (digit_t *dest, int first, int last) {
	int i;
	for (i = first; i <= last; i++) dest [i] = 0;
}

void reg_copy (digit_t *dest, const digit_t *src, int first, int last) {
	int i;
	for (i = first; i <= last; i++) dest [i] = src [i];
}

void reg_exch (digit_t *dest, digit_t *src, int first, int last) {
	int i, t;
	for (i = first; i <= last; i++) {
		t = dest [i];
		dest [i] = src [i];
		src [i] = t;
	}//for
}

static digit_t do_add (digit_t x, digit_t y, uint8_t carry, uint8_t base) {
	int res;

	res = x + y + ((act_reg->flags&carry)?1:0);
	if (res >= base) {
		res -= base;
		act_reg->flags |= carry;
	}//if
	else {
		act_reg->flags &= ~carry;
	}//else
	return (res);
}


static digit_t do_sub (digit_t x, digit_t y, uint8_t carry, uint8_t base) {
	int res;

	res = (x - y) - ((act_reg->flags&carry)?1:0);
	if (res < 0) {
		res += base;
		act_reg->flags |= carry;
	}//if
	else {
		act_reg->flags &= ~carry;
	}//else
	return (res);
}

void reg_add (digit_t *dest, const digit_t *src1, const digit_t *src2, int first, int last, uint8_t carry, uint8_t base) {
	int i;

	for (i = first; i <= last; i++) {
		int s2 = src2 ? src2[i] : 0;
		dest [i] = do_add (src1[i], s2, carry, base);
	}//for
}


void reg_sub (digit_t *dest, const digit_t *src1, const digit_t *src2, int first, int last, uint8_t carry, uint8_t base) {
	int i;

	for (i = first; i <= last; i++) {
		int s1 = src1 ? src1[i] : 0;
		int s2 = src2 ? src2[i] : 0;
		int d = do_sub (s1, s2, carry, base);
		if (dest) dest [i] = d;
	}//for
}


// $$$ if in decimal mode, do illegal digits get normalized?
void reg_test_equal (const digit_t *src1, const digit_t *src2, int first, int last, uint8_t carry) {
	int i;

	act_reg->flags |= carry;
	for (i = first; i <= last; i++) {
		int s2 = src2 ? src2 [i] : 0;
		//(*carry) &= (src1 [i] == s2);
		if ((act_reg->flags & carry) && (src1 [i] != s2))
			act_reg->flags &= ~carry;
	}//for
}


// $$$ if in decimal mode, do illegal digits get normalized?
void reg_test_nonequal (const digit_t *src1, const digit_t *src2, int first, int last, uint8_t carry) {
	int i;

	//*carry = false;
	act_reg->flags &= ~carry;
	for (i = first; i <= last; i++) {
		int s2 = src2 ? src2 [i] : 0;
		//(*carry) |= (src1 [i] != s2);
		if (src1 [i] != s2)
			act_reg->flags |= carry;
	}//for
}


void reg_shift_right (digit_t *reg, int first, int last) {
	int i;
	for (i = first; i <= last; i++) reg [i] = (i == last) ? 0 : reg [i+1];
}


void reg_shift_left (digit_t *reg, int first, int last) {
	int i;
	for (i = last; i >= first; i--) reg [i] = (i == first) ? 0 : reg [i-1];
}
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
